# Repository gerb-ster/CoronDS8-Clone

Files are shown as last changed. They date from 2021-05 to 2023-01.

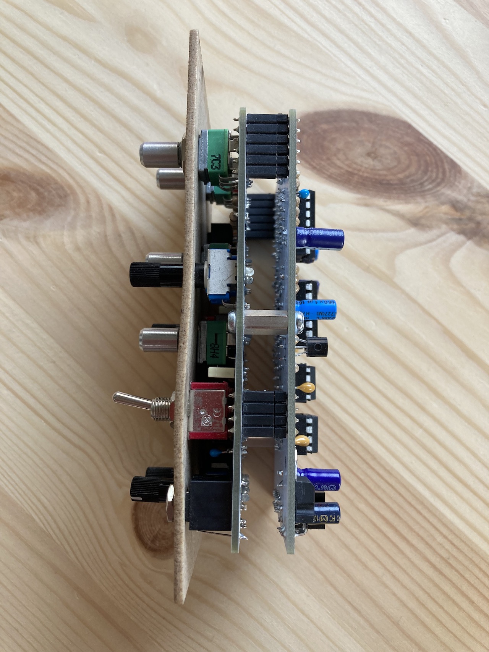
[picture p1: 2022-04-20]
images/IMG_1324.jpeg

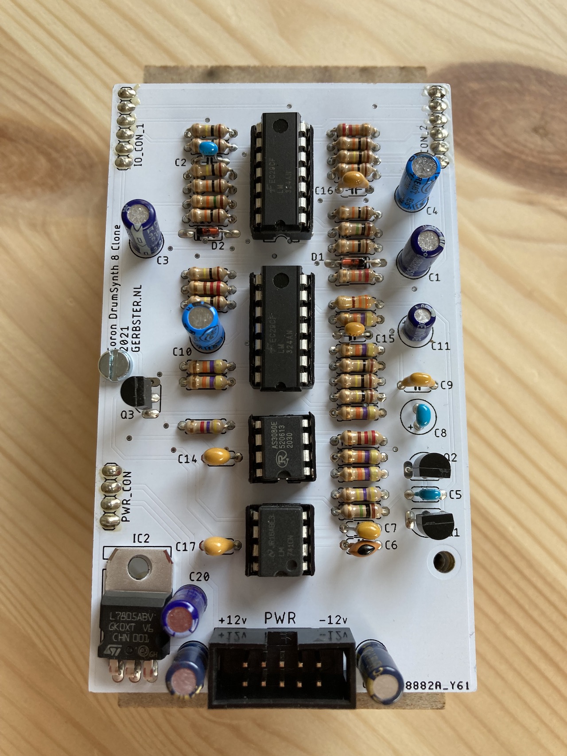
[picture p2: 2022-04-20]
images/IMG_1325.jpeg

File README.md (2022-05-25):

# CoronDS8 Clone

This is a clone of the famous Coron DS8 DrumSytnh unit from the seventies. I've adapted it 
to a Eurorack module and included a small mod, a on-off-on 'weird' toggle switch, which 
generates even spacier drum sounds.

## Status: (Almost) Finished

- done: first schematic & board design
- done: breadboard and test
- done: design frontpanel
- done: order PCB and build prototype
- done: fully test the prototype
- todo: buid a proper faceplate

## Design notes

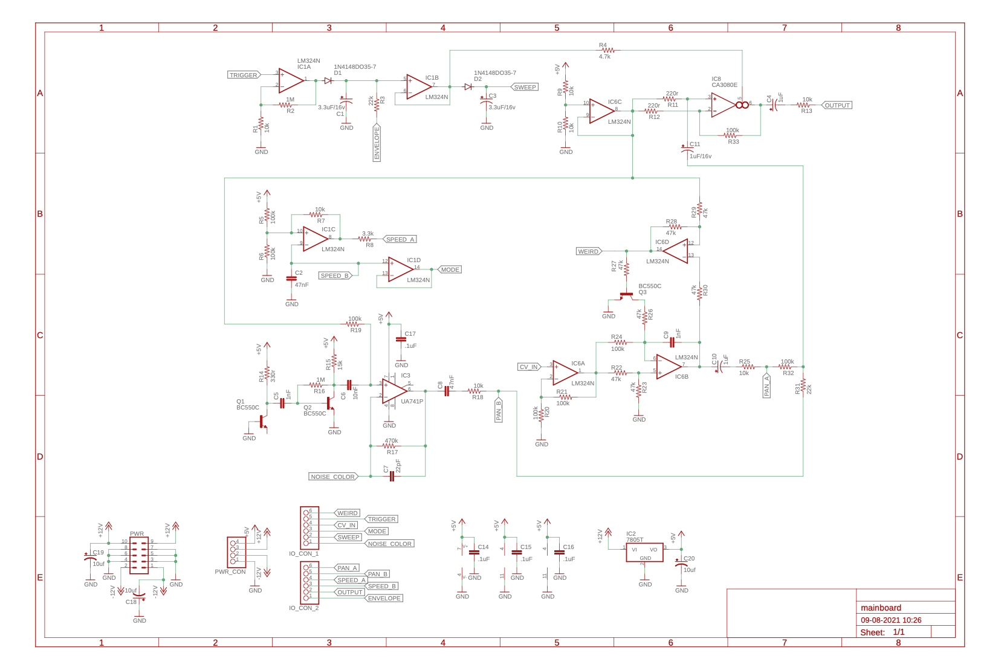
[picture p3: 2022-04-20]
images/CoronDS8-Clone-mainboard.png

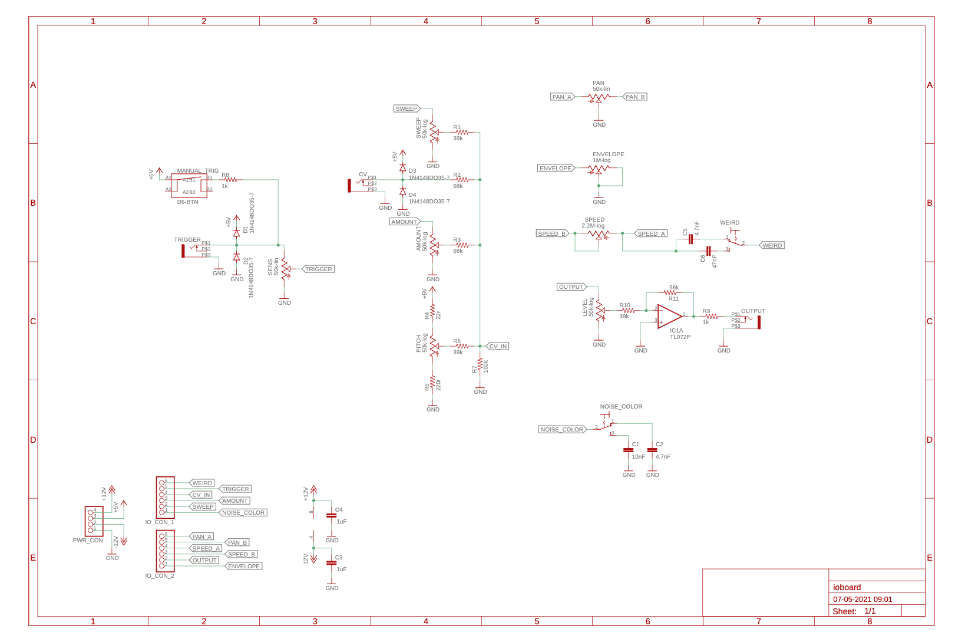
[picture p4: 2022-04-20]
images/CoronDS8-Clone-ioboard.png

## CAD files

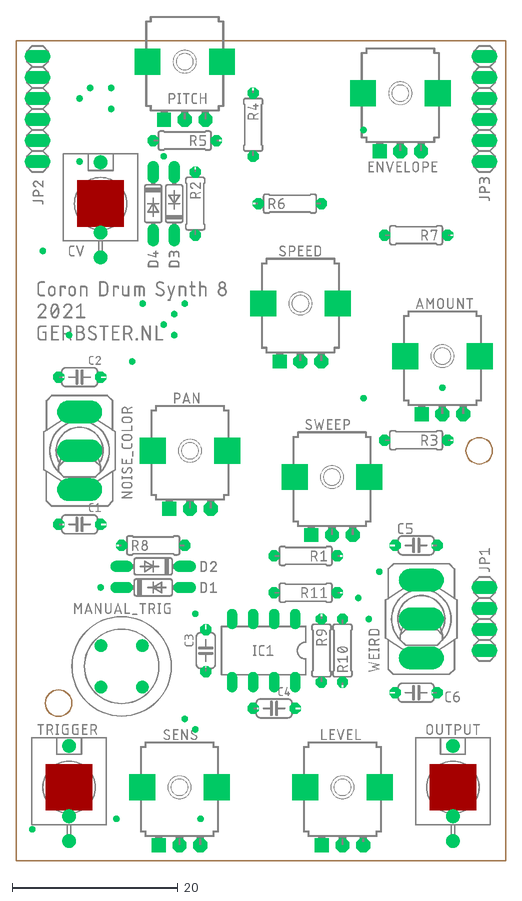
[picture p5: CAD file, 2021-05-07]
faceplates/coron-ds8-io.dxf
59.1 x 102.0

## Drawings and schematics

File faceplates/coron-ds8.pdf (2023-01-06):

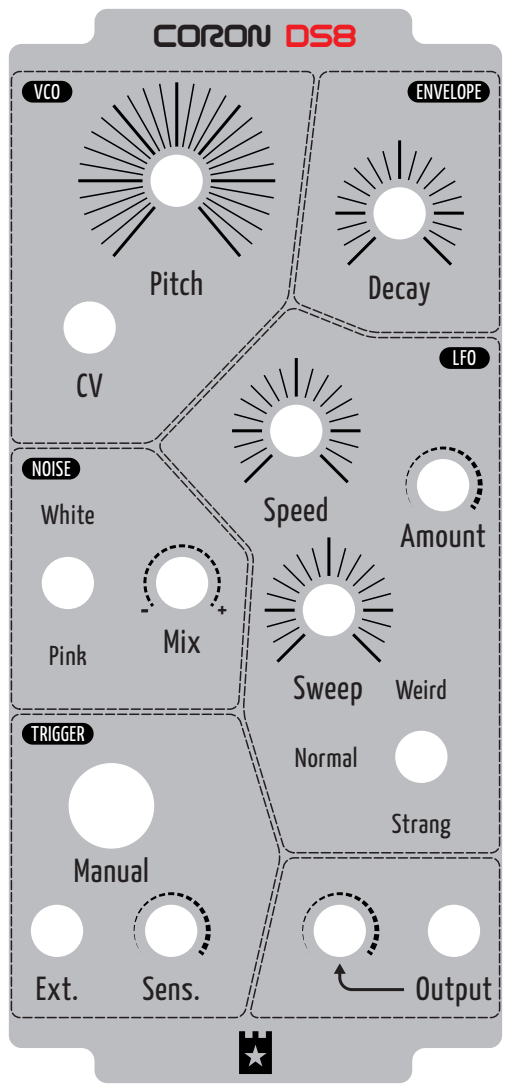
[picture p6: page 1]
Output; Pitch; Decay; Mix; Speed; Sweep; Amount; Manual; Ext.; Sens.; CORON DS8; VCO; LFO; ENVELOPE; NOISE; TRIGGER; Weird; Normal; Strang; White; Pink

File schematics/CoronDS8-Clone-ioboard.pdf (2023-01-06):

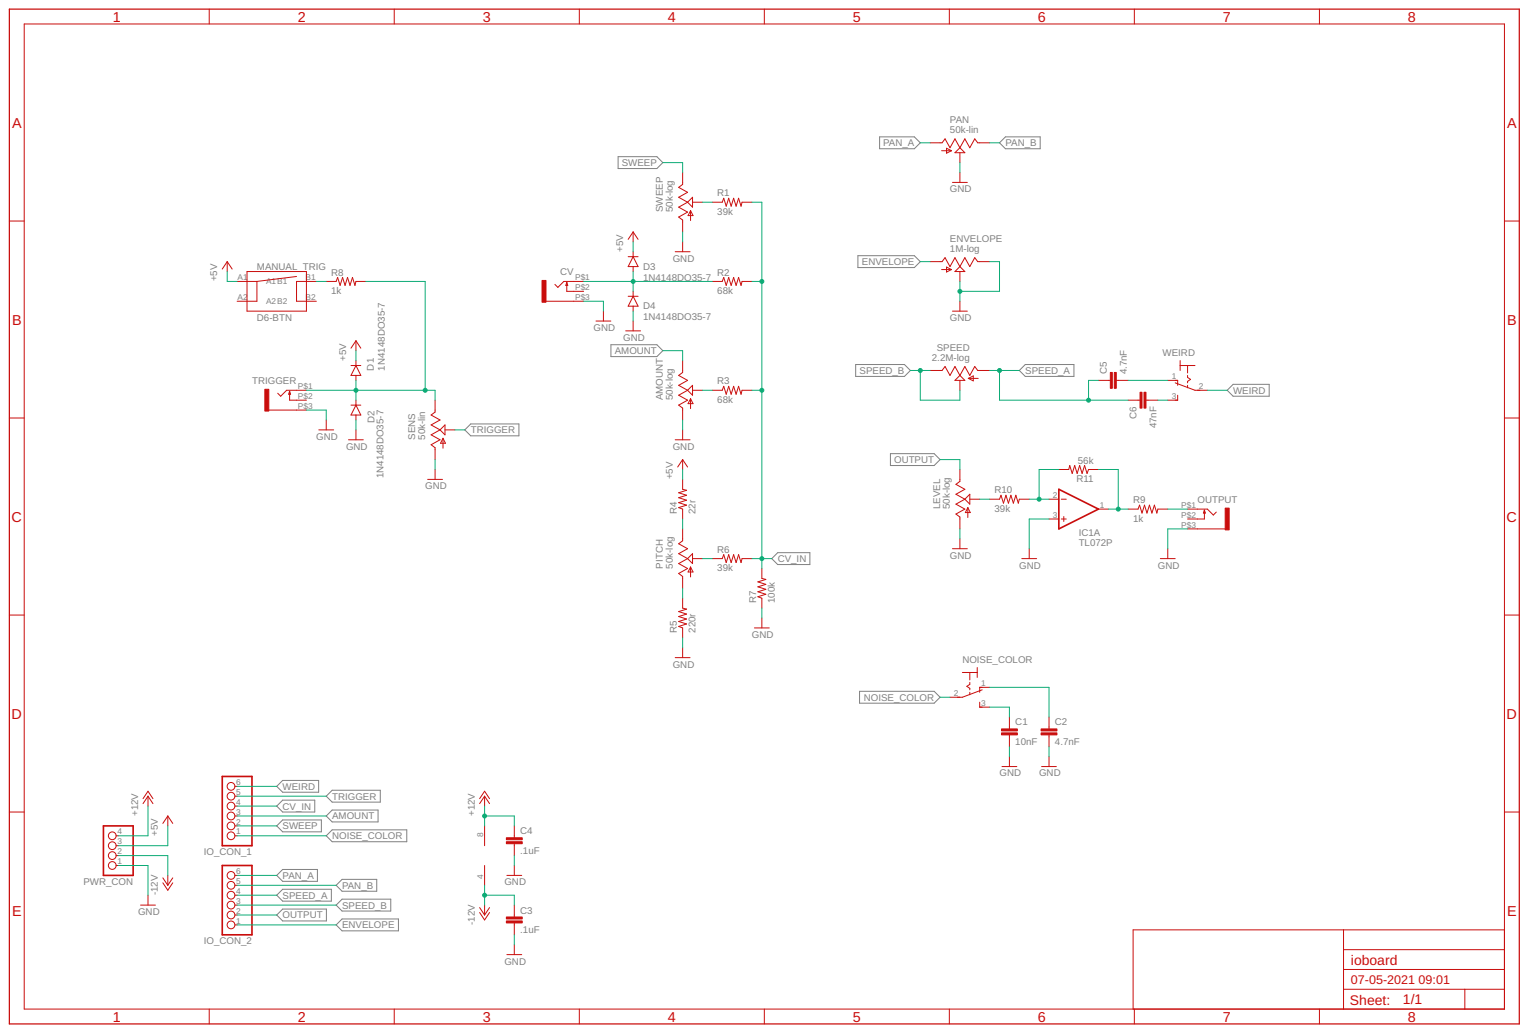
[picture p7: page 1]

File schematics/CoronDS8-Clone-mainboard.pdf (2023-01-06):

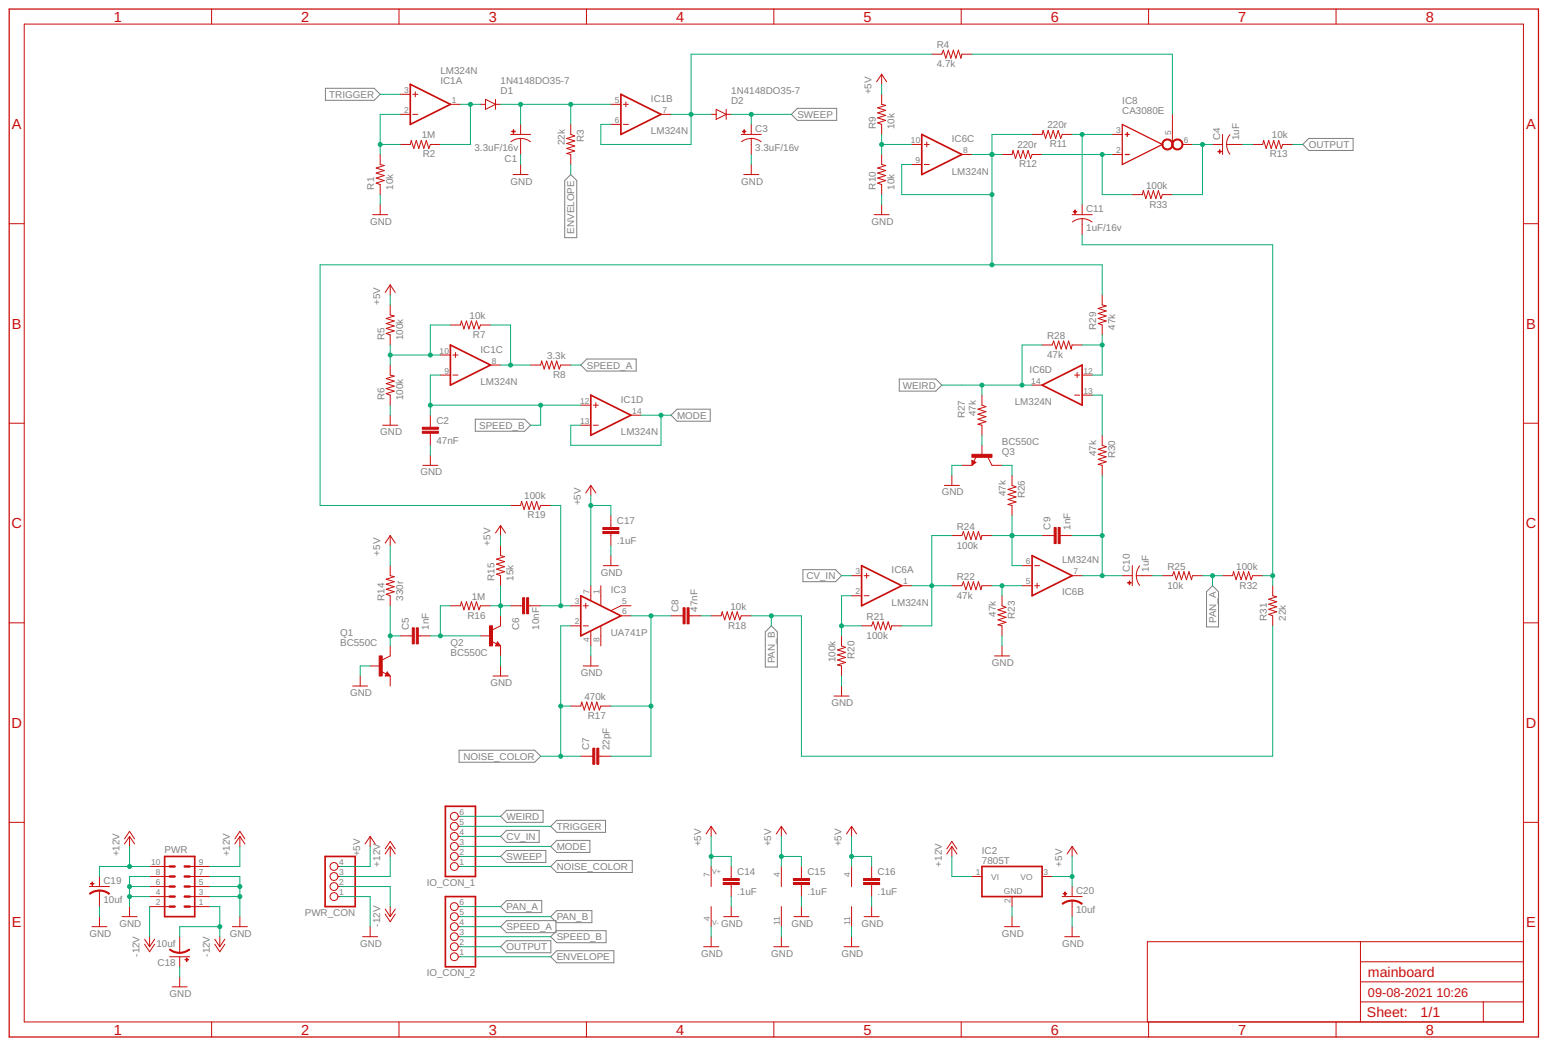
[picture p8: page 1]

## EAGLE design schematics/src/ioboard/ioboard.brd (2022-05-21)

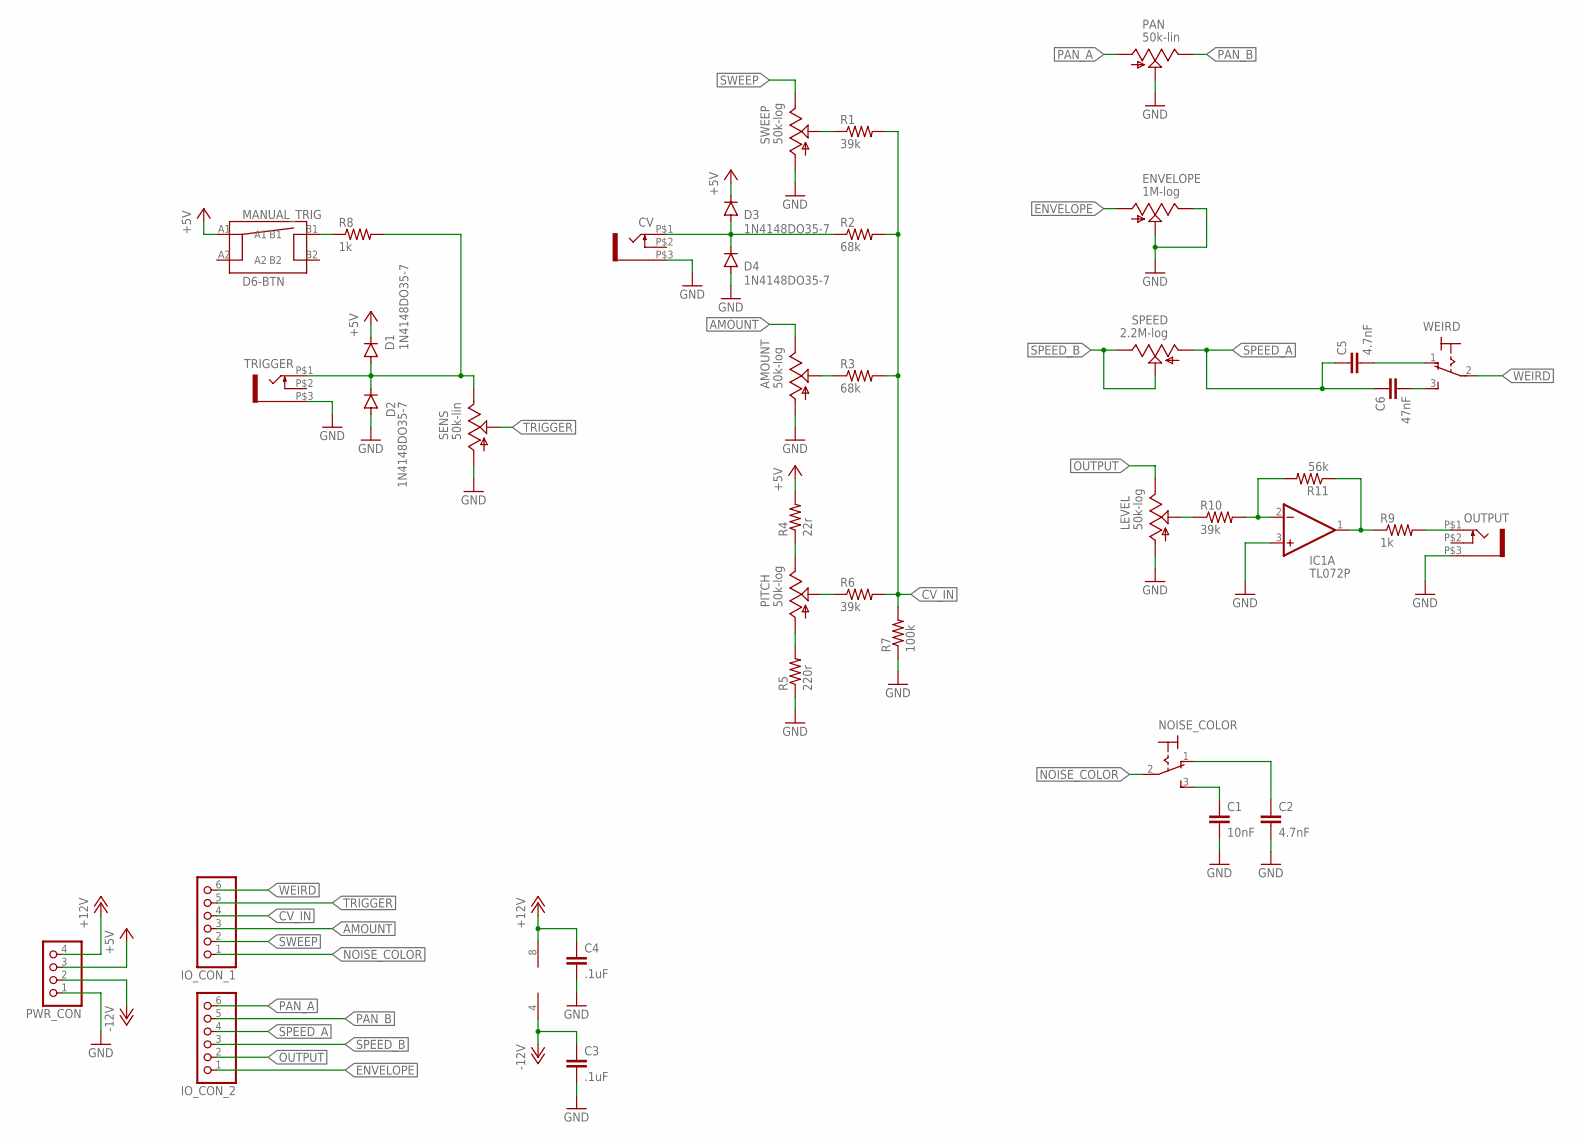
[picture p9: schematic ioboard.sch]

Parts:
AMOUNT: 50k-log; EVUF
C1: 10nF; C050-024X044
C2, C5: 4.7nF; C050-024X044
C3, C4: .1uF; C050-024X044
C6: 47nF; C050-024X044
CV: WQP-PJ301M-12_JACK
D1, D2, D3, D4: 1N4148DO35-7; DO35-7
ENVELOPE: 1M-log; EVUF
IC1: TL072P; DIL08
IO_CON_1, IO_CON_2: PINHD-1X6; 1X06
LEVEL: 50k-log; EVUF
MANUAL_TRIG: D6-BTN
NOISE_COLOR: M9040P
OUTPUT: WQP-PJ301M-12_JACK
PAN: 50k-lin; EVUF
PITCH: 50k-log; EVUF
PWR_CON: PINHD-1X4; 1X04
R1, R6, R10: 39k; 0207/7
R2, R3: 68k; 0207/7
R4: 22r; 0207/7
R5: 220r; 0207/7
R7: 100k; 0207/7
R8, R9: 1k; 0207/7
R11: 56k; 0207/7
SENS: 50k-lin; EVUF
SPEED: 2.2M-log; EVUF
SWEEP: 50k-log; EVUF
TRIGGER: WQP-PJ301M-12_JACK
WEIRD: M9040P

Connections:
+5V: D1.C, D3.C, MANUAL_TRIG.A1, PWR_CON.3, R4.2
+12V: C4.1, IC1.8 (V+), PWR_CON.4
-12V: C3.1, IC1.4 (V-), PWR_CON.2
AMOUNT: AMOUNT.3 (E), IO_CON_1.3
CV_IN: IO_CON_1.4, R1.2, R2.2, R3.2, R6.2, R7.2
ENVELOPE: ENVELOPE.1 (A), IO_CON_2.1
GND: AMOUNT.1 (A), C1.2, C2.2, C3.2, C4.2, CV.P$3 (1), D2.A, D4.A, ENVELOPE.2 (S), ENVELOPE.3 (E), IC1.3 (+IN), LEVEL.1 (A), OUTPUT.P$3 (1), PAN.2 (S), PWR_CON.1, R5.1, R7.1, SENS.1 (A), SWEEP.1 (A), TRIGGER.P$3 (1)
unnamed: PITCH.1 (A), R5.2
unnamed: PITCH.2 (S), R6.1
unnamed: PITCH.3 (E), R4.1
unnamed: AMOUNT.2 (S), R3.1
unnamed: CV.P$1 (2), D3.A, D4.C, R2.1
unnamed: R1.1, SWEEP.2 (S)
unnamed: C1.1, NOISE_COLOR.3 (S)
unnamed: IC1.2 (-IN), R10.2, R11.2
unnamed: C2.1, NOISE_COLOR.1 (O)
unnamed: MANUAL_TRIG.B1, R8.1
unnamed: C6.2, WEIRD.3 (S)
unnamed: OUTPUT.P$1 (2), R9.2
unnamed: IC1.1 (OUT), R9.1, R11.1
unnamed: LEVEL.2 (S), R10.1
unnamed: C5.2, WEIRD.1 (O)
unnamed: D1.A, D2.C, R8.2, SENS.3 (E), TRIGGER.P$1 (2)
NOISE_COLOR: IO_CON_1.1, NOISE_COLOR.2
OUTPUT: IO_CON_2.2, LEVEL.3 (E)
PAN_A: IO_CON_2.6, PAN.1 (A)
PAN_B: IO_CON_2.5, PAN.3 (E)
SPEED_A: C5.1, C6.1, IO_CON_2.4, SPEED.1 (A)
SPEED_B: IO_CON_2.3, SPEED.2 (S), SPEED.3 (E)
SWEEP: IO_CON_1.2, SWEEP.3 (E)
TRIGGER: IO_CON_1.5, SENS.2 (S)
WEIRD: IO_CON_1.6, WEIRD.2

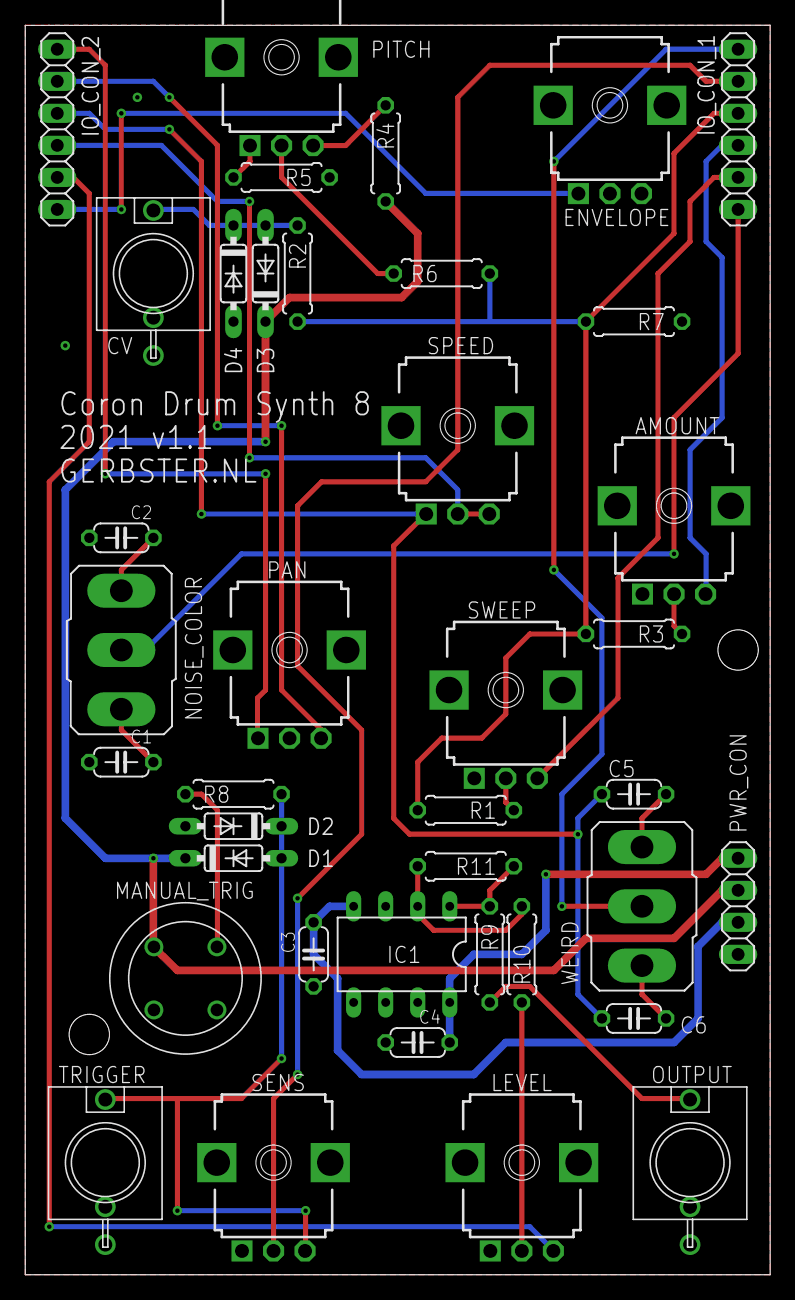
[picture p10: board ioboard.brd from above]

Board: 2 copper layers, 59.1 x 99.1 mm, 39 parts (0 on the bottom side), 32 nets.

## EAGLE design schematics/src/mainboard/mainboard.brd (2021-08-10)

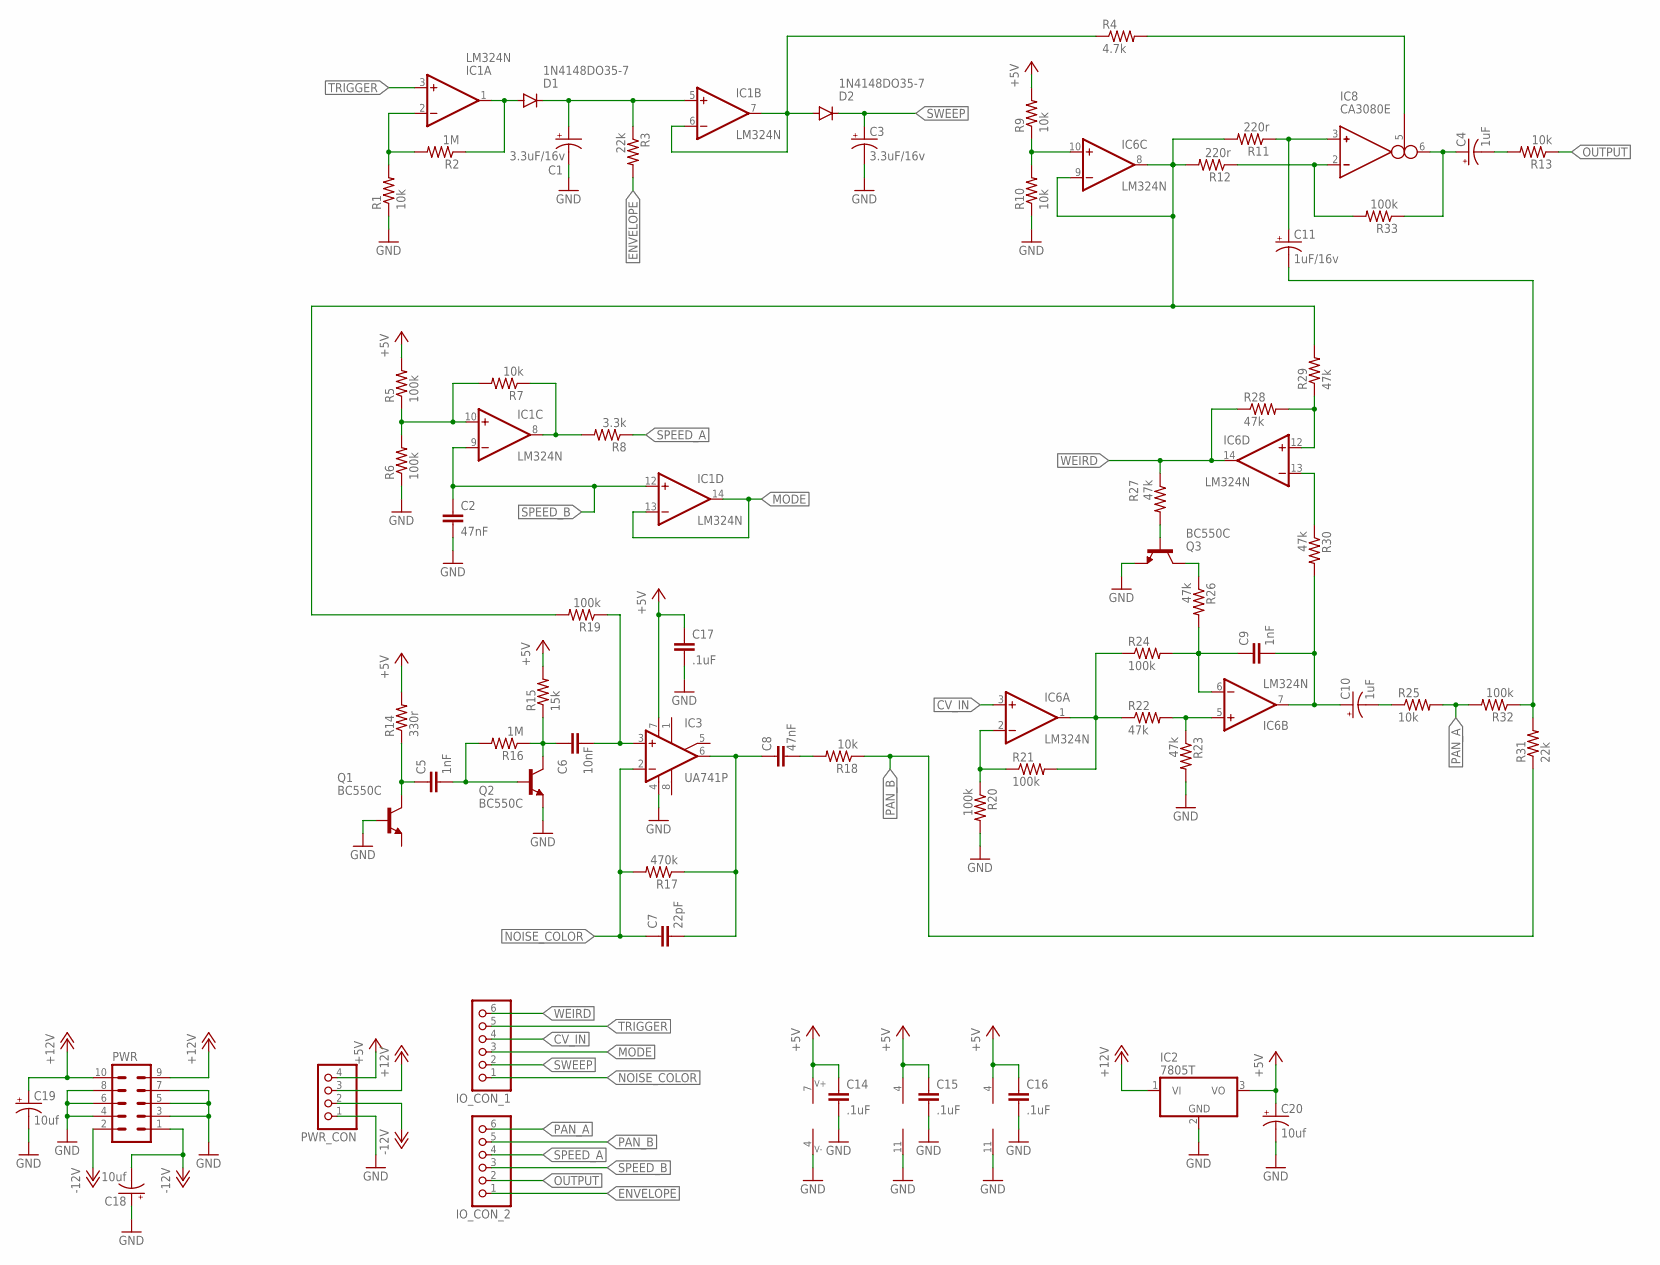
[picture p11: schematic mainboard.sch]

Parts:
C1, C3: 3.3uF/16v; E2,5-6
C2, C8: 47nF; C050-024X044
C4, C10: 1uF; E2,5-6
C5, C9: 1nF; C050-024X044
C6: 10nF; C050-024X044
C7: 22pF; C050-024X044
C11: 1uF/16v; E2,5-6
C14, C15, C16, C17: .1uF; C050-024X044
C18, C19, C20: 10uf; E2,5-5
D1, D2: 1N4148DO35-7; DO35-7
IC1, IC6: LM324N; DIL14
IC2: 7805T; TO220H
IC3: UA741P; DIL08
IC8: CA3080E; DIL08
IO_CON_1, IO_CON_2: PINHD-1X6; 1X06
PWR: ML10
PWR_CON: PINHD-1X4; 1X04
Q1, Q2, Q3: BC550C; TO92-EBC
R1, R7, R9, R10, R13, R18, R25: 10k; 0207/7
R2, R16: 1M; 0207/7
R3, R31: 22k; 0207/7
R4: 4.7k; 0207/7
R5, R6, R19, R20, R21, R24, R32, R33: 100k; 0207/7
R8: 3.3k; 0207/7
R11, R12: 220r; 0207/7
R14: 330r; 0207/7
R15: 15k; 0207/7
R17: 470k; 0207/7
R22, R23, R26, R27, R28, R29, R30: 47k; 0207/7

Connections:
+5V: C14.1, C15.1, C16.1, C17.1, C20.+, IC1.4 (V+), IC2.3 (VO), IC3.7 (V+), IC6.4 (V+), IC8.7 (V+), PWR_CON.4, R5.2, R9.2, R14.2, R15.2
+12V: C19.+, IC2.1 (VI), PWR.9, PWR.10, PWR_CON.3
-12V: C18.-, PWR.1, PWR.2, PWR_CON.2
CV_IN: IC6.3 (+IN), IO_CON_1.4
ENVELOPE: IO_CON_2.1, R3.2
GND: C1.-, C2.2, C3.-, C14.2, C15.2, C16.2, C17.2, C18.+, C19.-, C20.-, IC1.11 (V-), IC2.2 (GND), IC3.4 (V-), IC6.11 (V-), IC8.4 (V-), PWR.3, PWR.4, PWR.5, PWR.6, PWR.7, PWR.8, PWR_CON.1, Q1.B, Q2.E, Q3.E, R1.1, R6.1, R10.1, R20.2, R23.2
MODE: IC1.13 (-IN), IC1.14 (OUT), IO_CON_1.3
unnamed: IC1.2 (-IN), R1.2, R2.2
unnamed: D1.A, IC1.1 (OUT), R2.1
unnamed: C1.+, D1.C, IC1.5 (+IN), R3.1
unnamed: IC1.10 (+IN), R5.1, R6.2, R7.2
unnamed: D2.A, IC1.6 (-IN), IC1.7 (OUT), R4.1
unnamed: IC8.5 (I_BIAS), R4.2
unnamed: IC1.8 (OUT), R7.1, R8.2
unnamed: IC6.10 (+IN), R9.1, R10.2
unnamed: IC6.8 (OUT), IC6.9 (-IN), R11.2, R12.2, R19.2, R29.2
unnamed: C11.+, IC8.3 (IN_P), R11.1
unnamed: C4.+, IC8.6 (OUT), R33.1
unnamed: C5.1, Q1.C, R14.1
unnamed: C5.2, Q2.B, R16.2
unnamed: C4.-, R13.2
unnamed: C6.1, Q2.C, R15.1, R16.1
unnamed: C6.2, IC3.3 (+IN), R19.1
unnamed: C8.2, R18.2
unnamed: C7.2, C8.1, IC3.6 (OUT), R17.1
unnamed: IC6.5 (+IN), R22.2, R23.1
unnamed: IC6.2 (-IN), R20.1, R21.1
unnamed: IC6.1 (OUT), R21.2, R22.1, R24.1
unnamed: C9.1, IC6.6 (-IN), R24.2, R26.2
unnamed: C9.2, C10.+, IC6.7 (OUT), R30.2
unnamed: C10.-, R25.1
unnamed: Q3.C, R26.1
unnamed: Q3.B, R27.2
unnamed: IC8.2 (IN_N), R12.1, R33.2
unnamed: IC6.13 (-IN), R30.1
unnamed: C11.-, R31.2, R32.1
unnamed: IC6.12 (+IN), R28.2, R29.1
NOISE_COLOR: C7.1, IC3.2 (-IN), IO_CON_1.1, R17.2
OUTPUT: IO_CON_2.2, R13.1
PAN_A: IO_CON_2.6, R25.2, R32.2
PAN_B: IO_CON_2.5, R18.1, R31.1
SPEED_A: IO_CON_2.4, R8.1
SPEED_B: C2.1, IC1.9 (-IN), IC1.12 (+IN), IO_CON_2.3
SWEEP: C3.+, D2.C, IO_CON_1.2
TRIGGER: IC1.3 (+IN), IO_CON_1.5
WEIRD: IC6.14 (OUT), IO_CON_1.6, R27.1, R28.1

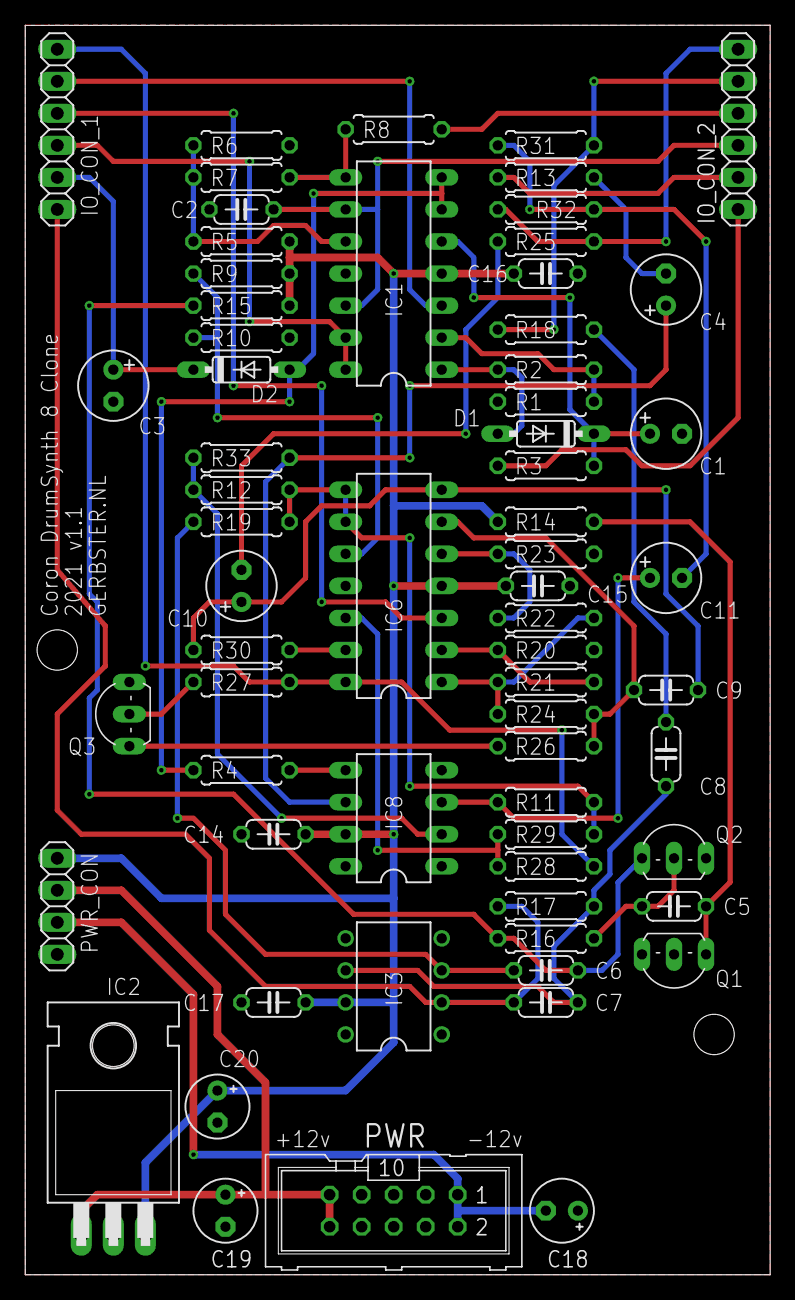
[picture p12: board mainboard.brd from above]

Board: 2 copper layers, 59.1 x 99.1 mm, 65 parts (0 on the bottom side), 46 nets.

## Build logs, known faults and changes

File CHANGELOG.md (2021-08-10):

# Changelog

All notable changes to this project will be documented in this file.

The format is based on [Keep a Changelog](https://keepachangelog.com/en/1.0.0/),
and this project adheres to [Semantic Versioning](https://semver.org/spec/v2.0.0.html).

## [1.0.0] - 2021-07-05

### Added

- Inintial repo setup

## [1.1.0] - 2021-08-09

### Changed

- Fixed dimensions issue, boards didn't line up
- Fixed some resistor values
- Fixed silkscreen issue

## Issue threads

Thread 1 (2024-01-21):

voltage mismatching between PCBs?

KeLaiFu, 2024-01-21:
I'm looking at building these boards and looking at the schematics, it looks like the power header between the boards doesn't match up (5v and 12v on pins 1 and 2 switch between boards)
It looks like the build photos on your website have used the same PCBs as the gerbers and .brd files. so, are they safe to build?

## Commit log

2021-05-07 Added files and structure
    [CoronDS8-Clone-ioboard.GBL, CoronDS8-Clone-ioboard.GBO, CoronDS8-Clone-ioboard.GBP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]
2021-06-15 Updated Schematics, Fixed Power Socket orientation
    [CoronDS8-Clone-ioboard.XLN, CoronDS8-Clone-mainboard.GBL, CoronDS8-Clone-mainboard.GBS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]
2021-08-06 Updated some schematics and docs
    [CoronDS8-Clone-ioboard.GBL, CoronDS8-Clone-ioboard.GBO, CoronDS8-Clone-ioboard.GBP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]
2021-08-10 Fixed some bugs and updated documentation
    [CoronDS8-Clone-ioboard.GTO, CoronDS8-Clone-ioboard.XLN, CoronDS8-Clone-mainboard.GBL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]
2022-04-20 Some updates & bugfixes
    [CoronDS8-Clone-ioboard.XLN, CoronDS8-Clone-mainboard.XLN, gerber_job.gbrjob]
2022-04-22 Fixed schematics & descriptions
    [CoronDS8-Clone-ioboard.XLN, CoronDS8-Clone-mainboard.XLN, gerber_job.gbrjob]
2022-05-17 Updated Firmware
    [CoronDS8-Clone-ioboard.XLN, CoronDS8-Clone-mainboard.XLN, gerber_job.gbrjob]
2022-05-18 Updated Faceplates
    [CoronDS8-Clone-ioboard.XLN, CoronDS8-Clone-mainboard.XLN, gerber_job.gbrjob]
2022-05-18 Fixed issues
    [CoronDS8-Clone-ioboard.XLN, CoronDS8-Clone-mainboard.XLN, gerber_job.gbrjob]
2022-05-21 Fixed schematics
    [CoronDS8-Clone-ioboard.GBL, CoronDS8-Clone-ioboard.GBS, CoronDS8-Clone-ioboard.GKO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]
2022-05-25 General updates
    [CoronDS8-Clone-ioboard.XLN, CoronDS8-Clone-mainboard.XLN, gerber_job.gbrjob]
2022-06-13 Faceplates & Bugfixes
    [drills.xln, gerber_job.gbrjob]
